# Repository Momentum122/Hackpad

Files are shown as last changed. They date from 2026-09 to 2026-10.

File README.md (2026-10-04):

# SmolPad 

SmolPad is an open-source, custom 3x3 mechanical macropad powered by the Seeed Studio XIAO RP2040 microcontroller. It features a 3x3 diode key matrix, an EC11 rotary encoder for volume control, and a 0.91" I2C OLED display for a plain text output (for now) , all housed in a custom 3D-printed case running KMK Firmware .

# Features

 **3x3 Key Matrix:** Direct-soldered MX mechanical switches with 1N4148 diodes .
 **EC11 Rotary Encoder:** Smooth volume adjustment and press-to-mute functionality.
 **0.91" I2C OLED Display:** 128x32 resolution driven by the SSD1306 display controller displaying status information.
 **Compact Case Design:** Custom 2-piece case secured with M3 heat-set brass inserts.
 **Easy Customization:** Powered by KMK / CircuitPython—edit shortcuts on the fly by modifying `main.py` like a USB drive file.

Keymap
 Row 0 
  i) Media play/pause
  ii) Brightness Increase 
  iii) Brighness Decrease
 Row 1 
  i) Super/Windows key ( i know this one is weird but the one on my keyboard doesnt work so i will use this for the timebeing).
  ii) Audio Mute 
  iii) Copy ( Ctrl + C)
 Row 2
  i) Cut (ctrl + x)
  ii) Paste (ctrl + v)
  iii) undo (ctrl + z)

Rotary Encoder 
 i) Clockwise Turn - Volume Up
 ii) Counter-Clockwise - Volume Down
 iii) Push Switch Press - Mute Toggle ( will be later used to switch layers)

OLED Display 
i) currently Displays only a single static text i.e. Smolpad active 

All the Above can and will be most likely changed later on .

# Project Structure

HackPad
 CAD
  Top.step
  Top.stl
  Bottom.step
  Bottom.stl
  Hack Club Knurled Knob.step
 PCB
  smolpad.kicad_pcb
  smolpad.kicad_pro
  smolpad.kicad_sch
  smolpad.step
  gerbers(final).zip
 firmwarefiles
  boot.py
  kb.py
  main.py
  lib 
  kmk 
Imagaes
  Case
   Bottom.png
   Combined.png
   Top.png
  PCB 3d model.png
  Schematic.pdf
 BOM.csv
 README.md

 Acknowledgements :- i) Usage of Ai for understanding features of Kicad/Onshape , Usage of ai for guidance in few areas like firmware , Usage of ai for identifying errors and resolving them
 ii) All resources are not owned by me (except case and Pcb however you are free to use them if you want to).  
 iii) Created with the guidance of https://hackpad.hackclub.com/guide , https://youtu.be/8WXpGTIbxlQ?si=IzrQN_IX_nW7LFwR  .
 iv) Built with support from the Hack Club grants and resoureces —massive thanks to them for funding the hardware and making this project a reality.
 v) Built for Stardance hackclub 
 CONTACT INFO :- mandeepswami2010@gmail.com

Suggestions / Issues / Complaint(s) are accepted and appreciated for the betterment of the macropad.

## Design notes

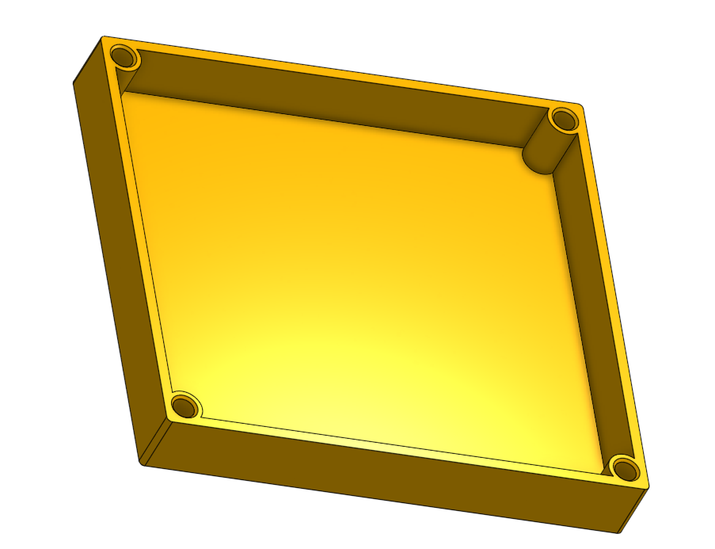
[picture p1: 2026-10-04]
Images/Case/Bottom.png

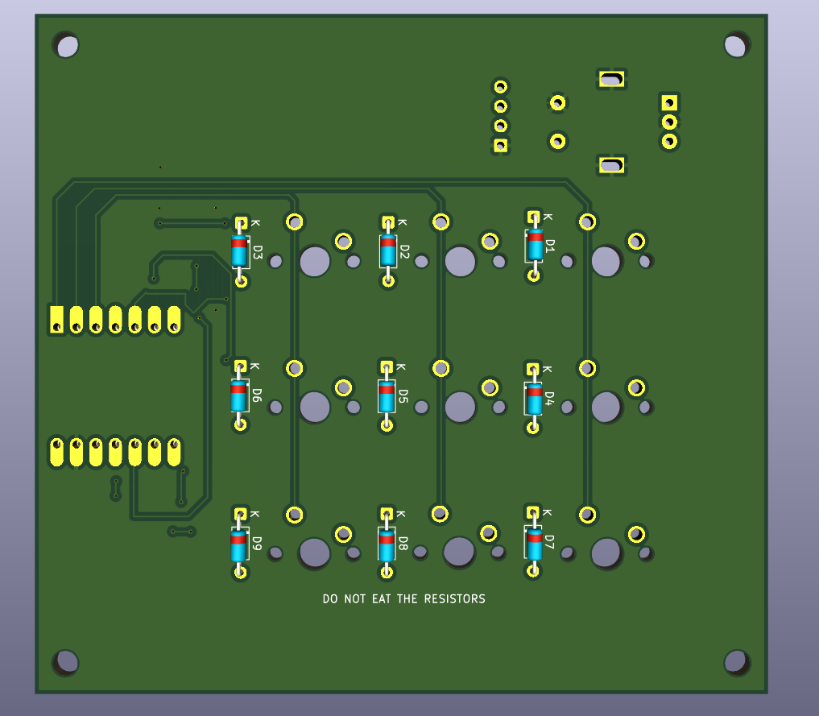
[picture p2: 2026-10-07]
Images/3d bottom Pcb.png

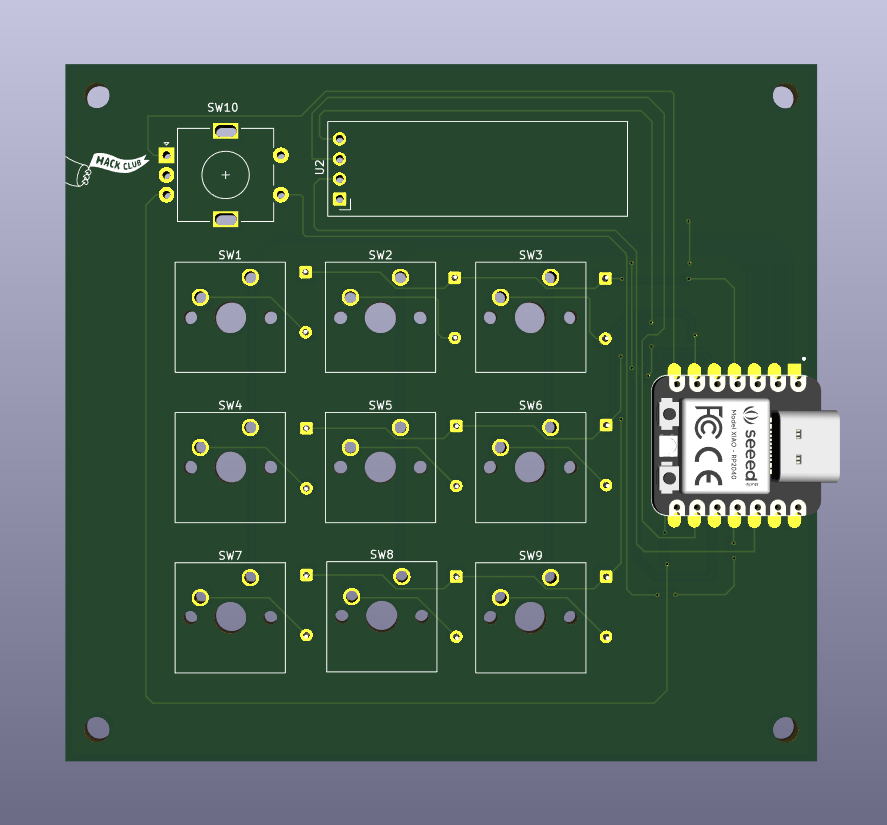
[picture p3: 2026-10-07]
Images/3d top pcb.png

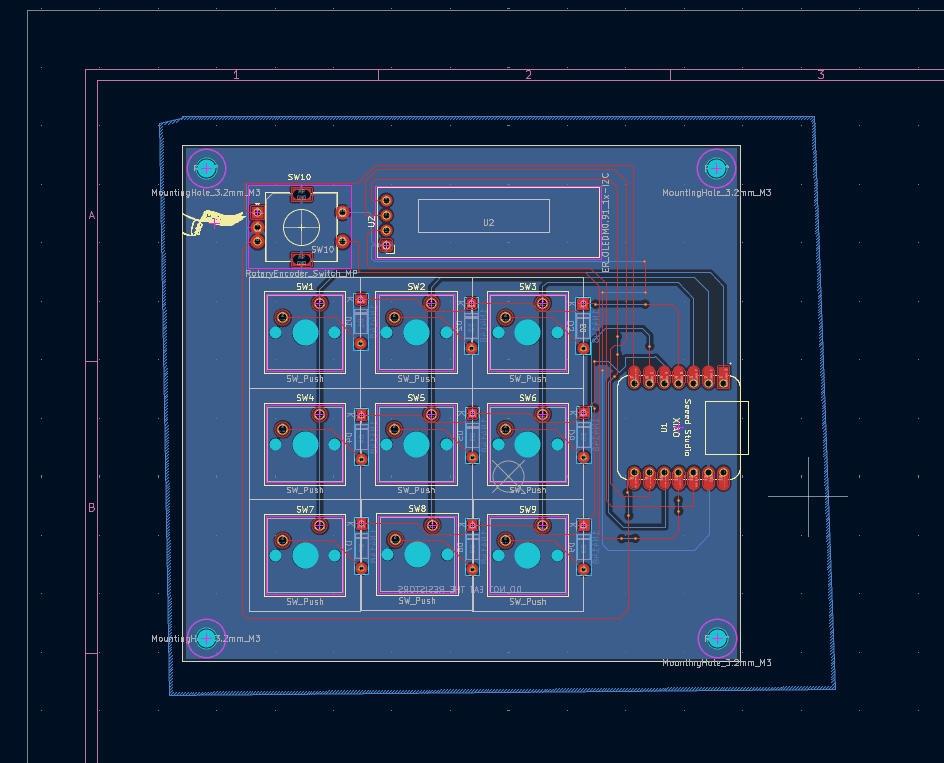
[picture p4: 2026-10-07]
Images/Pcb.png

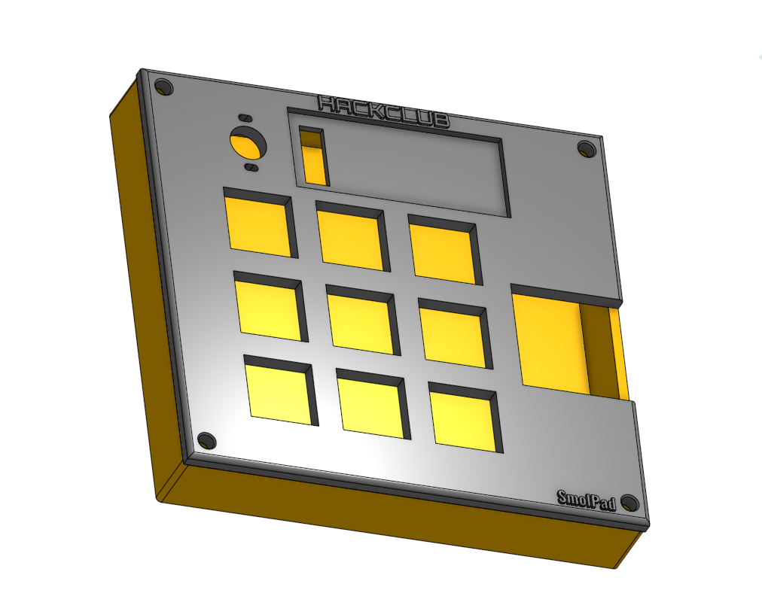
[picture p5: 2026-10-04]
Images/Case/Combined.png

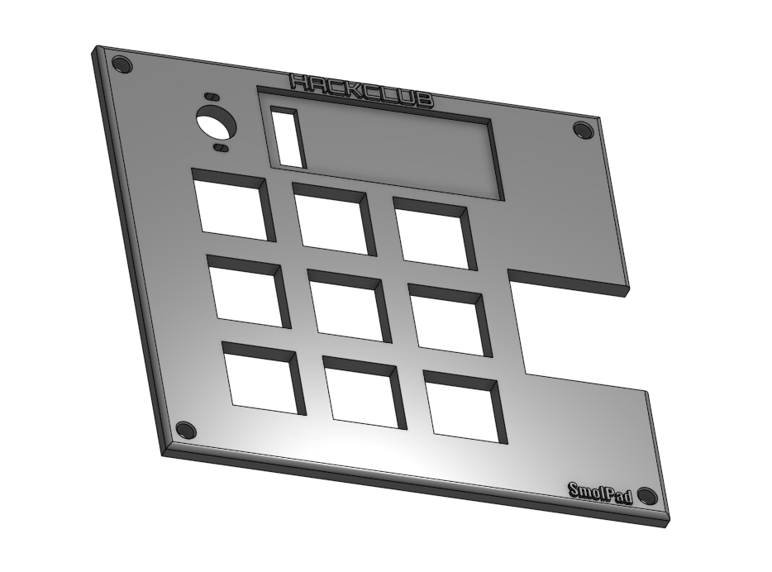
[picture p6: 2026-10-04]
Images/Case/Top.png

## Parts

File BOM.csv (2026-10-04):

All the components needed for this macropad design:
9x Cherry MX Switches
9x DSA Keycaps
4x M3x16mm screws
9x through-hole 1N4148 Diodes
1x 0.91 inch OLED display (128x32)
1x EC11 Rotary encoder
1x XIAO RP2040
= $$24.00 – $38.50
1x Case (2 printed parts + optional Rotary Encoder Cap)
= $2.00 – $5.00
5x SmolPad PCB's
= $5.30 (JLCPCB.com)
Soldering Iron Kit (This is my first Soldering so i am making sure to do it correctly so i am getting extra things to do it safely)
1x YIHUA X-4 Premium Soldering Iron Holder with Brass Wool, Cleaning Sponge and Solder Tip Slots
= ₹369.00 https://robu.in/product/yihua-x-4-premium-soldering-iron-holder-with-brass-wool-cleaning-sponge-and-solder-tip-slots/
1x Bakon BK609S Soldering Iron ( i am getting this because i am using lead free hasl so it requires higher tempratures)
= ₹1109.00 https://robu.in/product/bakon-bk609s-soldering-iron/
1x Solder Wire 0.8mm50g
= ₹289.00 https://robu.in/product/solder-wire-0-8mm50g/
1x Taparia 1405 Side Cutting Mini Plier
= ₹239 https://www.amazon.in/gp/product/B00P66NXIY/ref=ox_sc_act_title_2?smid=AJ6SIZC8YQDZX&psc=1
1x SP Professional Solder Sucker Desoldering Pump with 2 piece Copper Desoldering Wick
= ₹99 https://www.amazon.in/gp/product/B0H4KYJ2N2/ref=ox_sc_act_title_3?smid=A3C7Z4RVM9A3G1&psc=1
1x Geek Lab Solder Flux Paste, Amtech RMA-223 10CC Syringe
= ₹232 https://www.amazon.in/gp/product/B0GY4BG5RN/ref=ox_sc_act_title_1?smid=A2TAUOL95KBX1X&psc=1
Final Cost :-
  Electronics = $0 Covered by Hackpad Kit
  Case = $0 Covered by $8 Printing Legion Grant
  PCB = $0 Covered by $10 Hackpad PCB Grant
  Robu.in Cart (Iron + Stand + Solder Wire) ₹1,767 (~$18.30)- ₹1733.86($18) Covered by Hack Club Grant = ₹33.14 ( will be paid by me)
  Amazon.in Cart (Cutters + Sucker/Wick + Flux): ₹239 + ₹99 + ₹232 = ₹570
  Total Cost of Soldering Iron Kit = ₹2337
  Total Out-of-Pocket = ₹33.14 (Robu extra) + ₹570 (Amazon) = ₹603.14

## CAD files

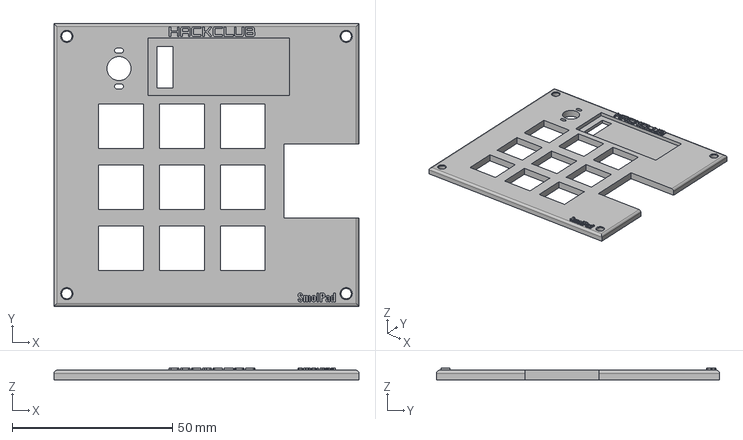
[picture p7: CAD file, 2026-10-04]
CAD/Top.step
95.3 x 88.4 x 3.60 mm

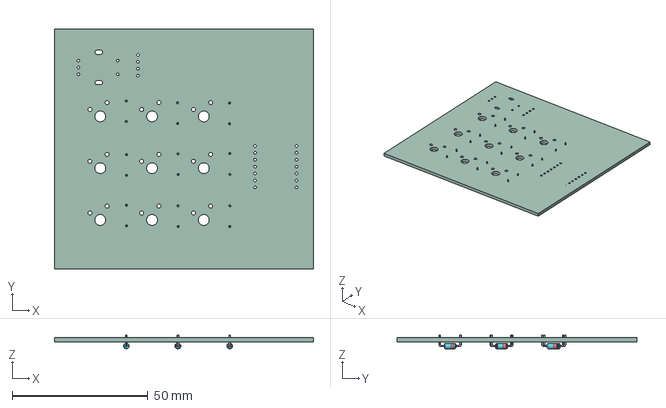
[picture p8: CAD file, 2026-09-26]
PCB/smolpad.step
95.3 x 88.4 x 5.01 mm
D_DO-35_SOD27_P7.62mm_Horizontal x 9
hackpad-unsaved-export-3Sq1gm_PCB

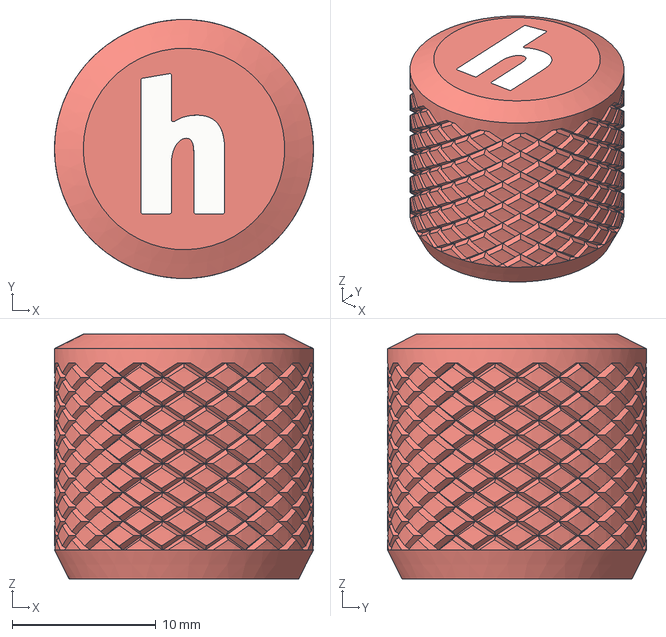
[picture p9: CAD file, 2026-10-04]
CAD/Hack Club Knurled Knob.step
18.0 x 18.0 x 17.0 mm
Base
H

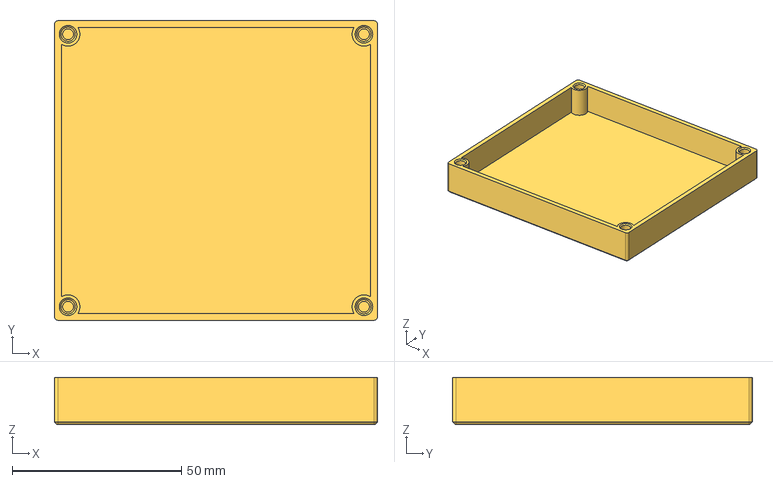
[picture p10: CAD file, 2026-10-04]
CAD/Bottom.step
95.3 x 88.4 x 14.0 mm

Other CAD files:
CAD/Bottom.stl
CAD/Top.stl

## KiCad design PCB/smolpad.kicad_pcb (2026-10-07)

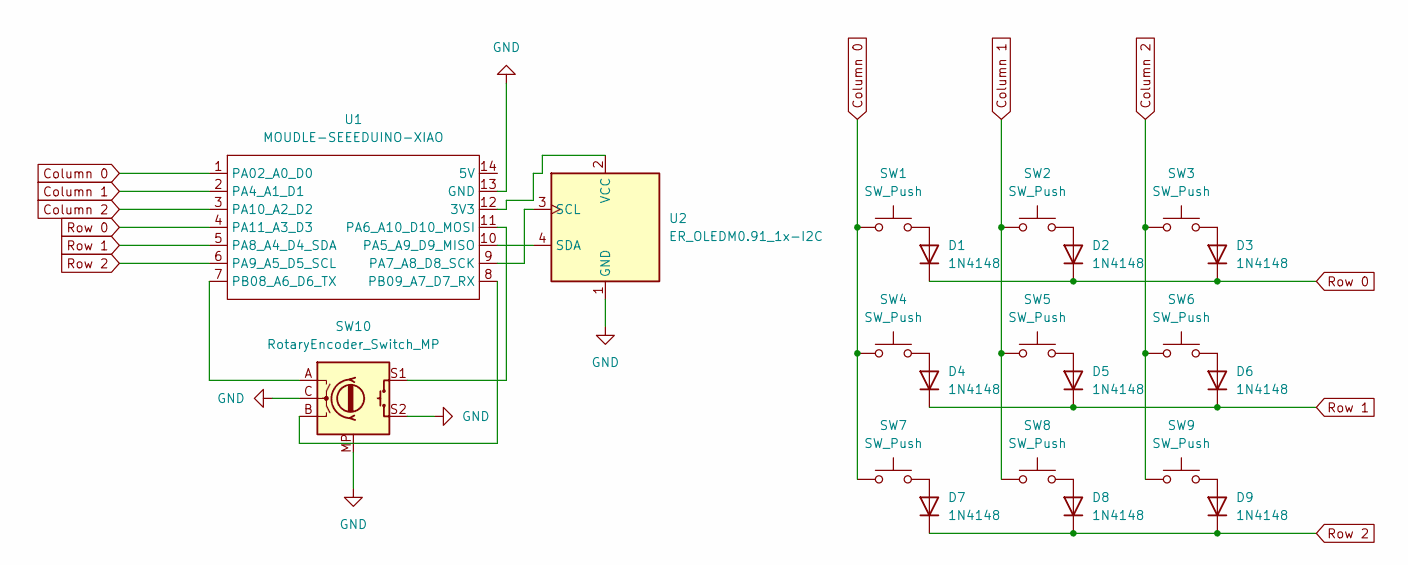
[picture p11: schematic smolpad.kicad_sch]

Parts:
D1, D2, D3, D4, D5, D6, D7, D8, D9: 1N4148; D_DO-35_SOD27_P7.62mm_Horizontal
SW1, SW2, SW3, SW4, SW5, SW6, SW7, SW8, SW9: SW_Push; SW_Cherry_MX_1.00u_PCB
SW10: RotaryEncoder_Switch_MP; RotaryEncoder_Alps_EC11E-Switch_Vertical_H20mm
U1: MOUDLE-SEEEDUINO-XIAO; XIAO-Generic-Hybrid-14P-2.54-21X17.8MM
U2: ER_OLEDM0.91_1x-I2C

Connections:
Column 0: SW1.1, SW4.1, SW7.1, U1.1 (PA02_A0_D0)
Column 1: SW2.1, SW5.1, SW8.1, U1.2 (PA4_A1_D1)
Column 2: SW3.1, SW6.1, SW9.1, U1.3 (PA10_A2_D2)
GND: SW10.C, SW10.MP, SW10.S2, U1.13 (GND), U2.1 (GND)
unnamed: D1.2 (A), SW1.2
unnamed: D2.2 (A), SW2.2
unnamed: D3.2 (A), SW3.2
unnamed: D4.2 (A), SW4.2
unnamed: D5.2 (A), SW5.2
unnamed: D6.2 (A), SW6.2
unnamed: D7.2 (A), SW7.2
unnamed: D8.2 (A), SW8.2
unnamed: D9.2 (A), SW9.2
unnamed: U1.12 (3V3), U2.2 (VCC)
unnamed: U1.10 (PA5_A9_D9_MISO), U2.4 (SDA)
unnamed: SW10.S1, U1.11 (PA6_A10_D10_MOSI)
unnamed: U1.9 (PA7_A8_D8_SCK), U2.3 (SCL)
unnamed: SW10.A, U1.7 (PB08_A6_D6_TX)
unnamed: SW10.B, U1.8 (PB09_A7_D7_RX)
Row 0: D1.1 (K), D2.1 (K), D3.1 (K), U1.4 (PA11_A3_D3)
Row 1: D4.1 (K), D5.1 (K), D6.1 (K), U1.5 (PA8_A4_D4_SDA)
Row 2: D7.1 (K), D8.1 (K), D9.1 (K), U1.6 (PA9_A5_D5_SCL)

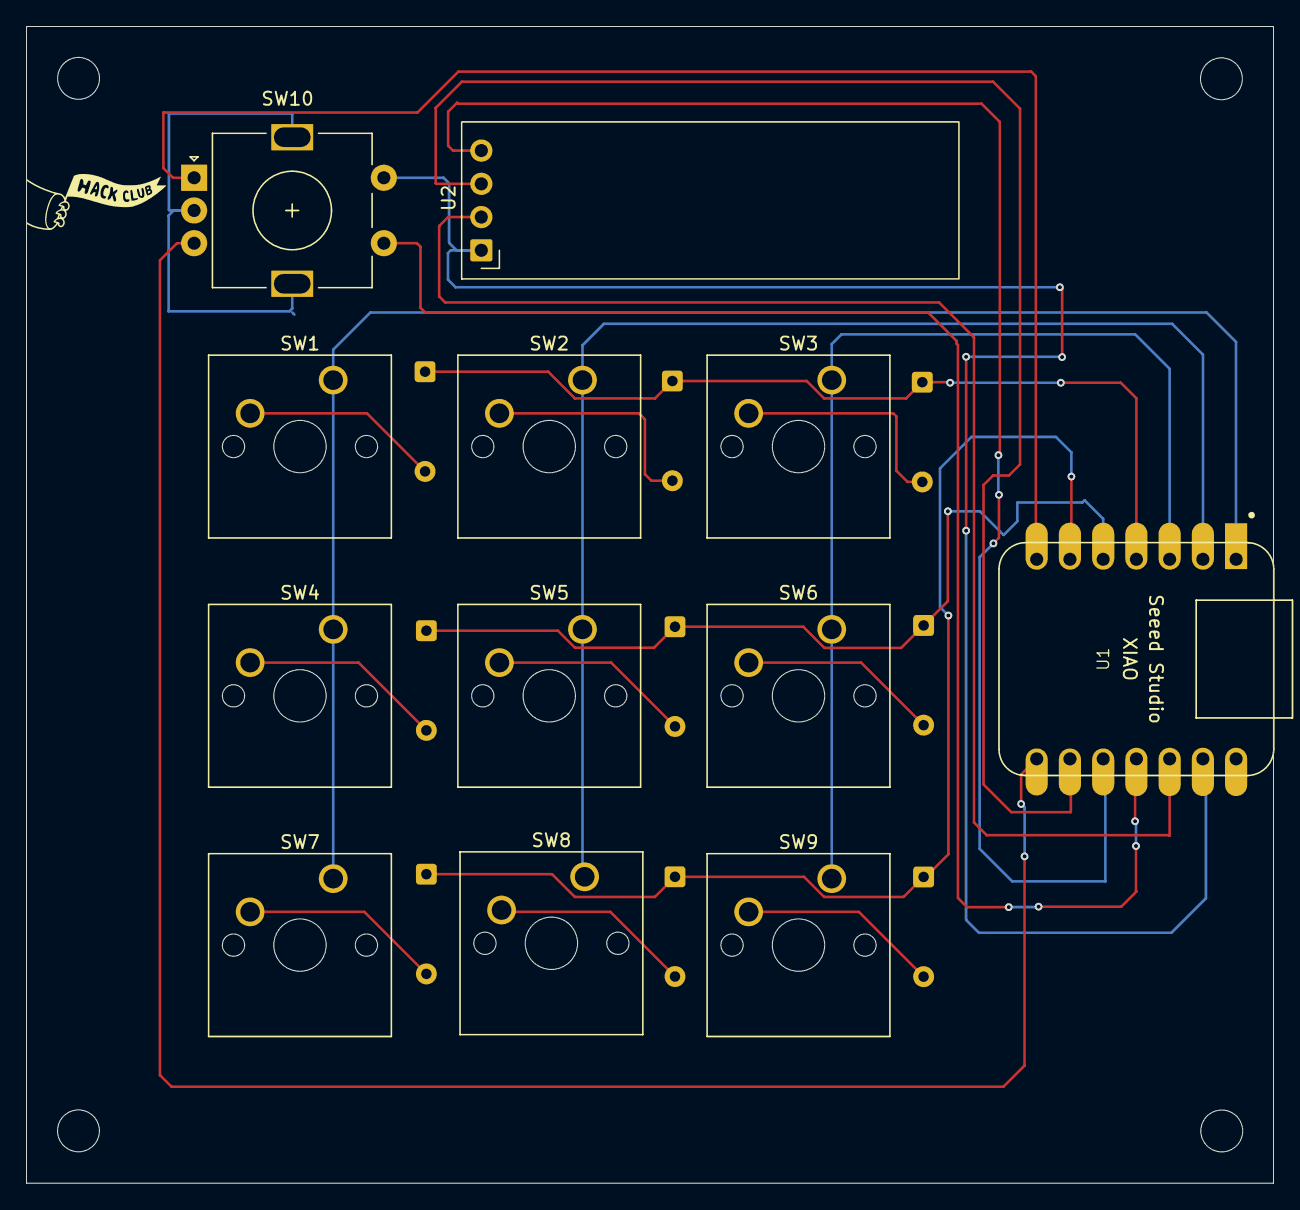
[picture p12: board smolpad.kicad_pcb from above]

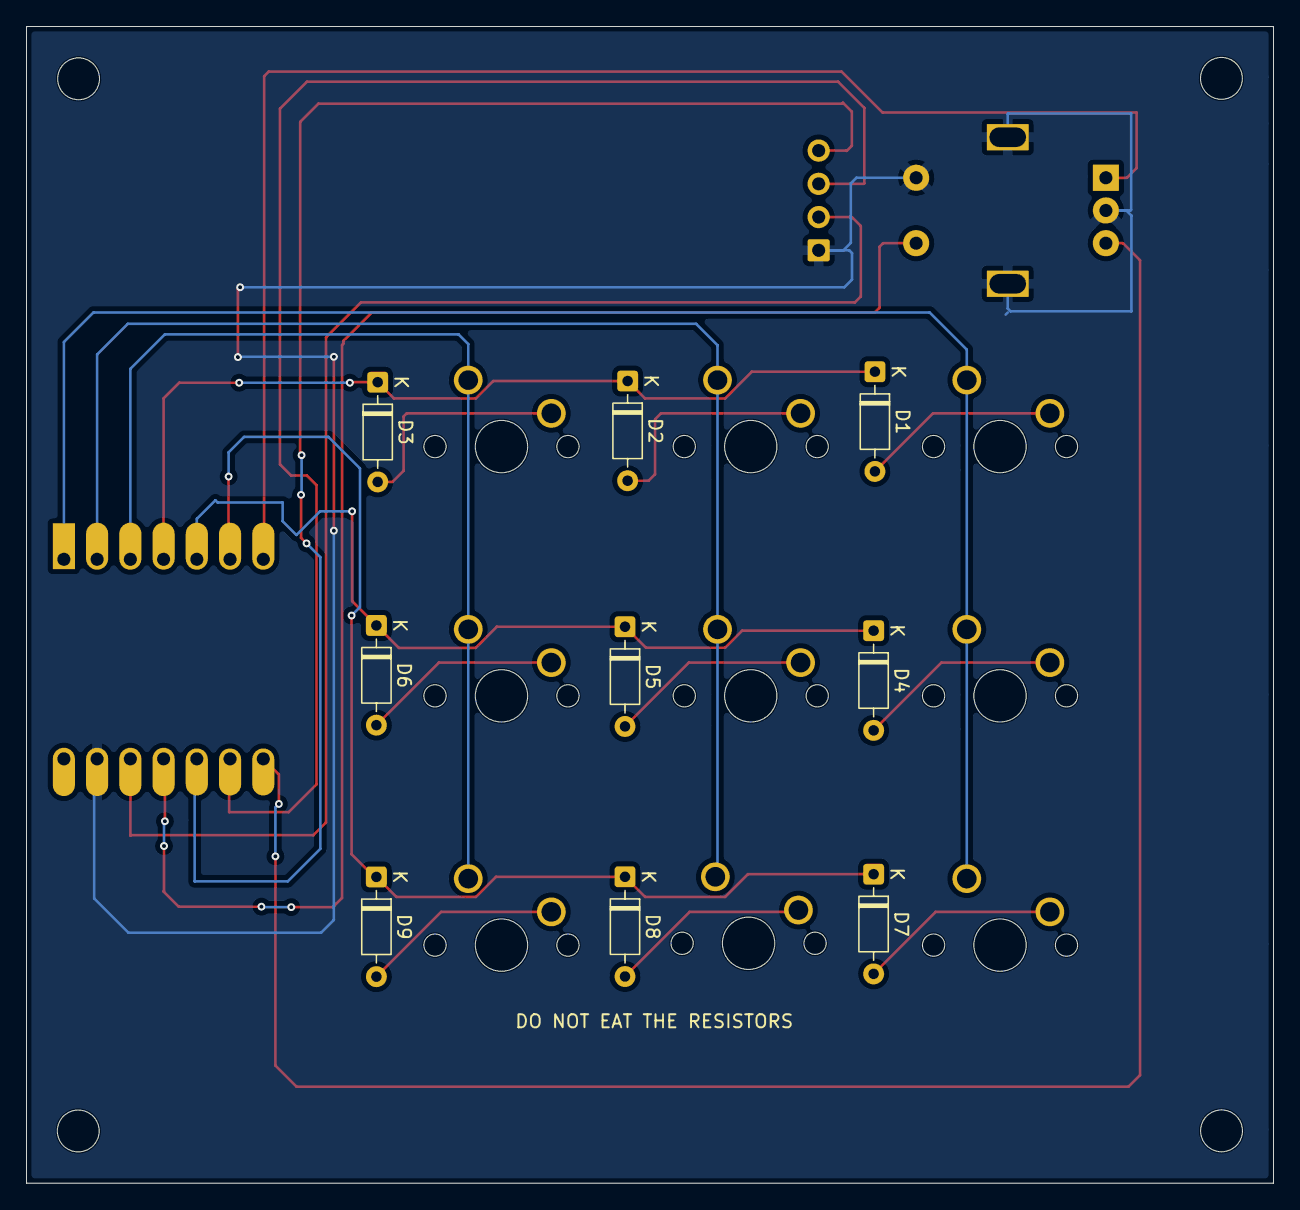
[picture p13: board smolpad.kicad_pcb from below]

Board: 2 copper layers, 95.3 x 88.4 mm, 21 parts (9 on the bottom side), 22 nets.

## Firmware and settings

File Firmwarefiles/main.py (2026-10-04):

import board
import busio
import displayio
import terminalio
from adafruit_display_text import label
import adafruit_displayio_ssd1306

from kb import SmolPad
from kmk.keys import KC
from kmk.modules.encoder import EncoderHandler
from kmk.extensions.media_keys import MediaKeys

keyboard = SmolPad()

media_keys = MediaKeys()
keyboard.extensions.append(media_keys)

encoder_handler = EncoderHandler()
encoder_handler.pins = ((board.D6, board.D7, board.D10),)
encoder_handler.map = (
    ((KC.AUDIO_VOL_UP, KC.AUDIO_VOL_DOWN, KC.AUDIO_MUTE),),
)
keyboard.modules.append(encoder_handler)


keyboard.keymap = [
    [
        KC.MEDIA_PLAY_PAUSE, KC.BRIU,       KC.BRID,
        KC.LGUI,             KC.AUDIO_MUTE, KC.LCTL(KC.C),
        KC.LCTL(KC.X),       KC.LCTL(KC.V), KC.LCTL(KC.Z),
    ]
]


displayio.release_displays()
i2c = busio.I2C(scl=board.D8, sda=board.D9)
display_bus = displayio.I2CDisplay(i2c, device_address=0x3C)

display = adafruit_displayio_ssd1306.SSD1306(display_bus, width=128, height=32)

splash = displayio.Group()
text_area = label.Label(
    terminalio.FONT,
    text="SmolPad Active",
    color=0xFFFFFF,
    x=10,
    y=16
)
splash.append(text_area)
display.root_group = splash

if __name__ == "__main__":
    keyboard.go()

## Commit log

2026-09-23 Almost Completed Schematic
    [hackpad.kicad_pcb, hackpad.kicad_sch]
2026-09-24 Schematic Complete
    Schematic complete currently routing
    [hackpad.kicad_pcb, hackpad.kicad_sch]
2026-09-25 Completed Routing and generated gerber files
    [hackpad.kicad_pcb, hackpad.kicad_sch]
2026-09-26 working on the case
    [hackpad.step]
2026-09-27 rotated XIAO
    [hackpad.kicad_pcb, hackpad.kicad_sch]
2026-10-04 Project Complete
    [BOM.csv, Bottom.step, Bottom.stl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]
2026-10-07 changed footprints
    [smolpad.kicad_pcb, smolpad.kicad_sch]
2026-10-18 Update pricing for SmolPad PCBs in BOM.csv
    Updated the price of SmolPad PCBs from ₹450.00 to ₹1,244.05 and adjusted the corresponding USD price.
2026-10-18 Revise BOM.csv with updated costs and totals
    Updated BOM with corrected values and formatting.
2026-10-18 Fix BOM.csv formatting and update totals
2026-10-18 Request additional funding in BOM.csv
    Updated the total out-of-pocket cost row to request additional funding.
2026-10-28 Update total out-of-pocket cost description in BOM.csv
2026-10-29 Update BOM by removing items and adjusting totals
    Removed several items from the BOM and updated total costs.
